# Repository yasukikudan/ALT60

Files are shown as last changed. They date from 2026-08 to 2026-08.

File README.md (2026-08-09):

# ALT60

61キーの60%サイズ手配線メカニカルキーボード。PCBを使わず、3Dプリントしたケースで組み立てる前提で設計している。最初から読みやすい配線設計、それに対応したファームウェア設定、その配線を前提に設計した3Dプリント用ケースを揃えている。このリポジトリはALT60自体の設計仕様であると同時に、Pro Microベースの手配線キーボードなら何にでも使い回せる小さなフレームワークでもある。

## ここに入っているもの

| | |
|---|---|
| [`docs/wiring_plan.html`](docs/wiring_plan.html) | 13×5マトリクスの配線表全体 — 61キーそれぞれがどのピアに乗るか、なぜそうなるか。 |
| [`docs/wiring_layout.html`](docs/wiring_layout.html) | 同じ配線を実際のキー配置に重ねた図 — はんだ付け中に開いておく用。 |
| [`docs/keymap.html`](docs/keymap.html) | 論理キーマップ: ベースレイヤー、Fnレイヤー、JIS/US記号補正。 |
| [`docs/case_design.html`](docs/case_design.html) | 3Dプリント用ケース仕様 — プレート、側壁、ネジボス、MCU用のくぼみ、打鍵傾斜まで全て寸法込み。 |
| [`firmware/`](firmware/) | ファームウェア本体。`keyboard_fw/board_config.h`がALT60固有の設定、`matrix_scan.h`/`keycode_output.h`は汎用。 |
| [`CLAUDE.md`](CLAUDE.md) | AIエージェントによる対話的ピン発見を使って手配線ボードを立ち上げるための指示書 — 別のボードでも使い回せるように書いてある。 |

## キーボード概要

- **61キー**、15U × 5行のレイアウト(Row1=14, Row2=14, Row3=13, Row4=12, Row5=8キー)。
- **スペースキーにスタビライザーなし** — 6.25Uのキーキャップの下に独立したスイッチを2個配置し、マトリクスに結線するのは1個だけ。もう1個は機械的な支持専用のダミースイッチ。
- **フルFnレイヤー**: Fキー、矢印、ナビゲーションクラスタ、メディアキー、独立したグレイブ(`` ` ``、Fn+Z)/チルダ(`~`、Fn+X)。
- **Macモード**(`Fn+Win`でトグル、EEPROM保存): Space両脇のCtrlキーがCmdを送るようになる。
- **実行時JIS/US記号補正**(`Fn+Menu`、EEPROMに保存) — USキーキャップのままWindowsが日本語(JIS)レイアウトになっている環境向け。
- USB経由の**NKRO**、[HID-Project](https://github.com/NicoHood/HID)の`NKROKeyboard`を使用。

## 配線を一言で言うと

列ピン(`D5`〜`D9`)がそれぞれ物理的な行を1本ずつ駆動する。行ピン(`D0`,`D1`,`D2`,`D3`,`D4`,`D10`,`D14`,`D15`,`D16`,`D18`,`D19`,`D20`,`D21`)が行内の左から位置を選ぶ。例外は2つだけ — Backspaceと`\`(それぞれRow1・Row2の14番目のキーで、行ピンが13本しかないため)、Row5の空いている行ピンスロットを間借りする。詳細と理由は[`docs/wiring_plan.html`](docs/wiring_plan.html)を参照。

## ケース

3Dプリント、2パーツ構成: トッププレート(スイッチ穴のみ)とボトムシェル(側壁一体型、小型Pro Micro+ユニバーサル基板用のくぼみ、壁に一体成形したネジボス — バラのスタンドオフ部品なし)。打鍵傾斜は約7.45°(手前18.0mm/奥33.1mm)。壁・ボス・穴すべての寸法を含む全体仕様は[`docs/case_design.html`](docs/case_design.html)を参照。

## ファームウェアのビルド

```bash
arduino-cli core install arduino:avr
arduino-cli lib install "HID-Project"
arduino-cli compile --fqbn arduino:avr:leonardo firmware/keyboard_fw
arduino-cli upload -p <COM_PORT> --fqbn arduino:avr:leonardo firmware/keyboard_fw
```

`firmware/keyboard_fw/board_config.h`は`docs/wiring_plan.html`から直接導いたALT60の目標設定であり、**まだ実機で配線を検証していない**。ALT60を実際に組む場合は`docs/wiring_layout.html`通りに配線したあと、まず`firmware/matrix_scanner/matrix_scanner.ino`を書き込んで、各キーが`board_config.h`の想定通りの(行, 列)に来ているか1つずつ確認してから信用すること — 立ち上げ手順の全体は`CLAUDE.md`を参照。

## このフレームワークで別のボードを組む場合

`firmware/keyboard_fw/matrix_scan.h`と`keycode_output.h`は完全に汎用で、ボード固有の情報は全て`board_config.h`から読み込む。`firmware/matrix_scanner/matrix_scanner.ino`が対話的なピン発見ツール。`CLAUDE.md`にはその全工程(実際に時間を食った失敗パターンも含めて)がまとめてあるので、AIエージェントが別の人の手配線ボードでも同じ立ち上げ手順を再現できる。

## ライセンス

BSD 3-Clause — [`LICENSE`](LICENSE)参照。公開前に著作権者名を記入すること。

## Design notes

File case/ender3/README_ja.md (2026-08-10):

# ALT60ケース Ender-3左右分割版

`case/original` のFIX済み原寸マスターを変更せず、Ender-3で出力できるようにトップとボトムを中央で左右分割した派生版です。

- トッププレートとボトムケースは左右2分割、合計4パーツです。
- 中央4本のM2.5ネジと完全なネジ受けを最優先し、丸棒・穴は位置合わせの補助とします。
- 独立した台座・柱・ブロックは作らず、底板と前後側壁へ横向きの丸棒と穴を直接形成します。
- 接手は前壁2本、底面6本、後壁2本の合計10本です。
- 丸棒を左・右から交互に一体成形し、反対側には対応する横穴を設けています。
- 丸棒は直径3.2 mm、差し込み長8.0 mm、穴は直径3.5 mm、深さ9.0 mm、先端面取り0.5 mmです。
- 通常の底厚2.5 mmは分割線付近で6 mm、通常の壁厚3 mmは前後壁の分割線付近で6 mmへ増厚します。
- 底板の丸棒・穴の中心は増厚後6 mmの板厚中央、底面からZ=3.0 mmです。前後壁の丸棒・穴も増厚後6 mmの壁厚中央へ置きます。
- 増厚範囲は中央から左右20 mmで、左右16〜20 mmの範囲を斜面にして滑らかにつなぎます。
- 補強は内側だけに加え、ケース外形は変更しません。
- 外枠の外側へ出る突起や別体部品はありません。
- 分割部は0.30 mmの組立クリアランスを設けています。
- 中央部の前後に左1本・右1本ずつ、合計4本のM2.5縦ネジを配置しています。
- ネジ位置は X=-8/+8 mm、Y=-45/+45 mmです。
- トップ側にはM2.5通し穴と局所補強、ボトム側には欠けない完全なネジ受けを設けています。
- トッププレートから垂直にネジを締め、左右ボトムを同時に固定します。
- 全出力パーツは最大外寸200 mm未満であることを自動検査します。

組立時は左右ボトムを同じ高さに合わせ、10本の丸棒を対応する穴へ水平方向から同時に差し込みます。その上に左右トップを載せ、中央4本のM2.5ネジを先に締めてから外周ネジを締めます。初回は直径差0.3 mmで試し刷りし、プリンタの実寸に応じて `SOCKET_D` を調整してください。

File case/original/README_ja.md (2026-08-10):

# ALT60ケース v1

`alt60_case.py` は、ALT60リポジトリの物理配列を使ったCadQuery 2.xスクリプトです。

- 外形: 305.75 × 115.25 mm
- Cherry MX穴: 14 × 14 mm（6.25Uスペースバーは中央＋左右±50 mmの支持穴）
- 壁3 mm、床2.5 mm、トッププレート1.6 mm
- トップ／ボトム外周角: R3 mm
- ケース固定: M2.5 × 12、通し穴2.9 mm、ヒートセットインサート用3.5 mm下穴（使用するインサートに合わせて要調整）
- ケースネジ軸: トップから机に対して鉛直（傾斜プレートに対して約6.9°の斜め穴）
- トップネジ周囲: φ10 mm、局所厚約4 mm（通常部1.6 mm）
- ボトム受けボス: φ10 mm
- 60 × 70 mmユニバーサル基板: 後方中央、ケースと平行に傾斜、M2.5 × 4
- 基板下面から内底まで: 15 mm
- USB開口: 後壁中央、18 × 10 mm、R2（Micro-USB／USB-Cケーブルの樹脂モールド用余裕を含む）
- ケース高: 前14.0 mm、後28.0 mm（60×70 mm基板の前縁下に底厚を残すため）
- ユニバーサル基板とESP32: トッププレートと平行に約7.45°傾斜
- 写真の60×70 mm基板固定: φ7 mmのM2.5ボス4本、下穴2.0 mm（暫定で中心から左右±25、前後±30 mm）
- 基板の全周を開放し、四方から配線を通せる構造
- Ender-3左右分割対策: 前後とも分割線の中心X=0に固定点（左右半分ずつ造形）
- 幅の1/4・3/4位置（中心から約±76.4 mm）にも前後それぞれ固定点
- 60×70 mm基板中心はX=-108 mm（範囲X=-138〜-78 mm、完全に左半分側）
- ESP32とUSBは基板内でさらに左へ12 mm寄せてX=-120 mm
- 左後の1/4位置ネジだけX=-70 mmへ調整し、基板と両側ボスの間に約3 mm確保
- ピン逃げ: 中央54×64 mm、基板下面から深さ4 mm
- ESP32実装想定: ピンヘッダをユニバーサル基板へ直接はんだ付け
- ESP32上側実装高: 8 mm、切断後の裏ピン逃げ: 3 mm
- ESP32ピン専用逃げ: 約30×48 mm、深さ3 mm（基板中央）

## 生成

```powershell
python alt60_case.py
```

フルサイズのSTEP/STLと、Ender-3向け左右分割STLを同じフォルダに出力します。分割版は中央に0.30 mmの組立隙間を設けた単純二分割です。初号機では接着または裏面ブリッジ板で結合してください。

## 印刷前に確認する値

1. 実物ユニバーサル基板の穴位置（初期値は中心から±30、±20 mm）
2. ESP32のUSB中心高さ（初期値はユニバーサル基板上面から10.3 mm）
3. M2.5ヒートセットインサート指定の下穴径
4. 14 mm MX穴のテスト片（プリンタにより0.1〜0.2 mm補正）

元ALT60寸法では基板下面15 mmを確保できません。傾斜基板の前縁側が最小になるため、ピンを短く切り、初回印刷前に実物との干渉を確認してください。CQ-editorでは組立状態と分解状態を同時表示します。

分割STLはEnder-3のベッドに収まりますが、トッププレートは平置き、ボトム左右は底面を下にして印刷してください。トッププレートは長尺なので、反り止めとしてブリムを推奨します。

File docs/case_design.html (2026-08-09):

# ALT60(オールライフタイムキーボード) — 3Dプリント用ケース設計仕様

3Dプリンター(STL)前提の設計。バラのスタンドオフ部品は使わず、側壁を持つ完全な一体シェルとしてケースを構成する。トッププレートは側壁の上に直接乗せてネジ止めするだけで、側壁自体がスイッチ/配線用の空洞を作る。

①トッププレート(スイッチ穴+ネジボス用の縁)、②ボトムシェル(側壁+床+Pro Micro/基板用のくぼみを一体成形)の2パーツで完結する。

一般的なキーボードと同じく手前が低く、奥(背面)が高い傾斜を付ける。ケース奥行き115.25mm(側壁+ベゼル込み)に対し、手前18.0mm/奥33.1mm(角度約7.45°)を採用した。

厚み・高さ諸元(Z方向)
項目 | 寸法 | 備考
打鍵傾斜角 | 約7.45 ° | 手前18.0mm/奥33.1mmの高さ差(奥行き115.25mm)から算出
ケース全体高さ・手前(Row5/スペース側) | 18.0 mm | 底面(接地面)からトッププレート上面まで
ケース全体高さ・奥(Row1/USB側) | 33.1 mm | 手前18.0mm + 奥行き115.25mm × tan(7.45°)
ベゼル幅(壁内側〜スイッチ列) | 7.0 mm | 四辺とも確保。ネジボスがスイッチ穴と干渉しないための余白
トッププレート厚み | 3.0 mm | MX穴がスナップで保持できる標準的な厚み(傾斜方向に対して一定)
側壁の高さ(内部空洞の深さ) | 10.0 mm | スイッチ本体+手配線の取り回し分。傾斜方向に対して一定、トッププレートはこの壁の上端に直接乗る
側壁の厚み | 3.0 mm | シェル外周を1周する壁
ネジボス外径 | 8.0 mm | 壁の外面に接する位置に配置(壁厚みだけに頼らない、独立して自立する太さ)
ネジ穴・トッププレート側(クリアランス) | φ2.2 mm | M2ねじの軸が自由に通る貫通穴。ここはネジを受けない
ネジ下穴・シェル側(セルフタップ) | φ1.6 mm | M2セルフタップねじがここに食い込んで固定される。ボス高さ=側壁高さ10.0mmぶん深さがあるので保持力は十分
ボトムシェル床面の厚み・手前 | 5.0 mm | 18.0 − プレート3.0 − 壁10.0
ボトムシェル床面の厚み・奥 | 20.1 mm | 33.1 − プレート3.0 − 壁10.0。手前から奥へ直線的に厚みが増える
くぼみの深さ | 6.0 mm | Pro Micro+ユニバーサル基板+はんだ面のクリアランス込み

USBコネクタ用切り欠き
項目 | 寸法 | 備考
幅 | 10.0 mm | Micro-USB-B(実測幅約7.5mm)・USB-C(実測幅約8.5mm)どちらでも余裕を持って通る幅
高さ | 5.0 mm | コネクタ実高さ+印刷公差分の余裕
角丸半径 | 1.0 mm | 応力集中を避けるための丸め
切り欠き位置 | 側壁を貫通 | 壁厚3.0mm+くぼみ縁までを通し、背面(Row1側)の壁に開ける

キーキャップ外形(参考線)

スイッチ穴(結線あり)

スイッチ穴(支持のみ・未結線)

側壁(トッププレートは縁の帯、シェルは実際の壁)

ネジボス(外径8.0mm、壁に接して自立、M2、8箇所)

くぼみの外形(一体成形)

USB切り欠き

## ①トッププレート(スイッチ穴+ネジボス用の縁、厚み3.0mm)

スイッチ面285.75 × 95.25mm + 四辺7.0mmベゼル + 側壁厚み3.0mm = 外形305.75 × 115.25mm。

## ②ボトムシェル(側壁+床+くぼみを一体成形)

トッププレートと同じ外形(305.75 × 115.25mm)。側壁が空洞を作り、くぼみは床に彫り込む。バラのスタンドオフ部品は不要。

## ③断面イメージ(傾斜込み、組み立て時)

底面は水平(接地面)、手前18.0mm・奥33.1mmで約7.45°の傾斜。床厚は手前5.0mm→奥20.1mmと直線的に変化し、くぼみは厚みが確保できる奥側に配置。

### スペーサー(標準オフ部品)なしの完全ケース

以前案のバラのスタンドオフ(円柱ピンでプレートと底板を浮かせる方式)をやめ、側壁を持つ一体シェルに変更。側壁がそのままスイッチ/配線用の空洞を作り、トッププレートは側壁の上端に直接ネジ止めする。パーツ数が減り、組み立て時に位置決めもしやすい。

### 打鍵傾斜(手前が低く奥が高い)

底面(接地面)は水平のまま、プレート厚み3.0mm・壁高さ10.0mmは傾斜方向に対して一定に保ち、床の厚みだけを手前5.0mm→奥20.1mmへ直線的に変化させることで約7.45°の傾斜を作る。折りたたみ式の脚は使わず、ケース自体の形状で傾斜を固定する設計。

### スペースキー: 2スイッチ支持方式

6.25U幅の下にスイッチを2個配置(中心から左右1.25Uずつ)。結線するのは1個だけ(既存の行D20・列index4、ファームウェア変更なし)。もう1個は電気的に未接続で、キーキャップを水平に支えるためだけの「ダミースイッチ」。スタビライザーワイヤーが不要になる。

### ネジボスの強度(壁の中央に置かない)

初期案は壁厚3.0mmの中心線上にボスを置いていたため、実際には壁からはみ出た部分に強度がなく、印刷しても割れる設計になっていた。今回、ボス自体を外径8.0mmの独立した円柱にして壁の外面に接する位置に置き直し、壁の厚みだけに頼らずボス単体で強度が出るようにした。あわせて壁内側とスイッチ穴の間に7.0mmのベゼルを確保し、ボスがスイッチ穴と干渉しないようにした。四隅4箇所+上辺(Row1側)内側2箇所+左右辺中央2箇所の計8箇所、トッププレートとシェル両方で同じ位置に穴を開けて揃える。

### ネジ穴とネジを受ける穴は別物

トッププレート側はクリアランス穴(φ2.2mm)でネジの軸が自由に通るだけ。実際にネジを受けて締結するのはシェル側の下穴(φ1.6mm、セルフタップ用)で、ボスの高さ=側壁高さ10.0mm分の深さがあるので保持力も十分。同径の穴を両方に開けるとネジが効かない/プレートが浮くので、必ず径を変える。

### くぼみは一体成形、奥側の厚い床に配置

3Dプリントは平面から直接くぼみを彫り込めるので、レーザー加工向けの「フレーム層+底板の貼り合わせ」は不要。傾斜によって床が自然に厚くなる奥側(Row1/USB側)にくぼみを置いたため、以前のような局所的な底面の厚み増し(バルジ)は不要になった。印刷はくぼみ・スイッチ穴が上向きになる姿勢ならサポート材なしで出せる。

### 基板・Pro Microのサイズ

小型ユニバーサル基板 60×40mm、Pro Micro 18×33mmを想定したくぼみ・取り付け穴。実際に使う基板寸法とネジ穴ピッチ(ユニバーサル基板は2.54mm格子)に合わせて微調整する。

### 配線

行13本+列5本=計18本の配線がすべてこのくぼみへ集まる想定。各スイッチの実際の結線経路は手配線のため個別には図示していない(keymap_by_pin.md参照)。側壁で囲まれた高さ10mmの空洞がトッププレート裏の配線スペースになる。

### 穴寸法・印刷メモ

スイッチ穴14×14mm、1Uピッチ19.05mm(FDM印刷はレーザーのようなケルフ補正は不要。穴が小さめに出る場合はスライサー側で0.1〜0.2mmのホール補正を使う)。ネジボス穴はM2ねじ想定(セルフタップ or 圧入インサート)。

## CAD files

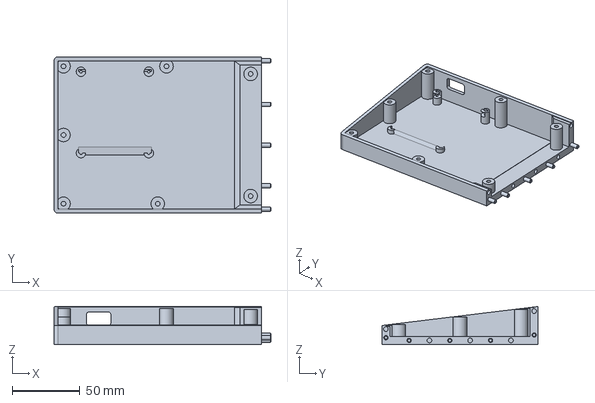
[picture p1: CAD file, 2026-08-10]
case/ender3/bottom/bottom_left.step
159.9 x 115.2 x 28.0 mm

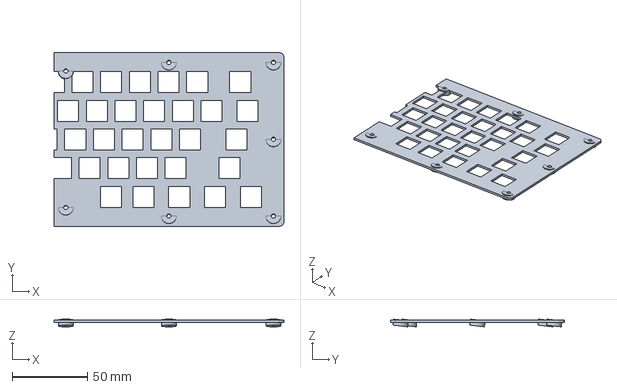
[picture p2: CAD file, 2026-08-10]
case/ender3/top/top_right.step
152.7 x 115.2 x 5.18 mm

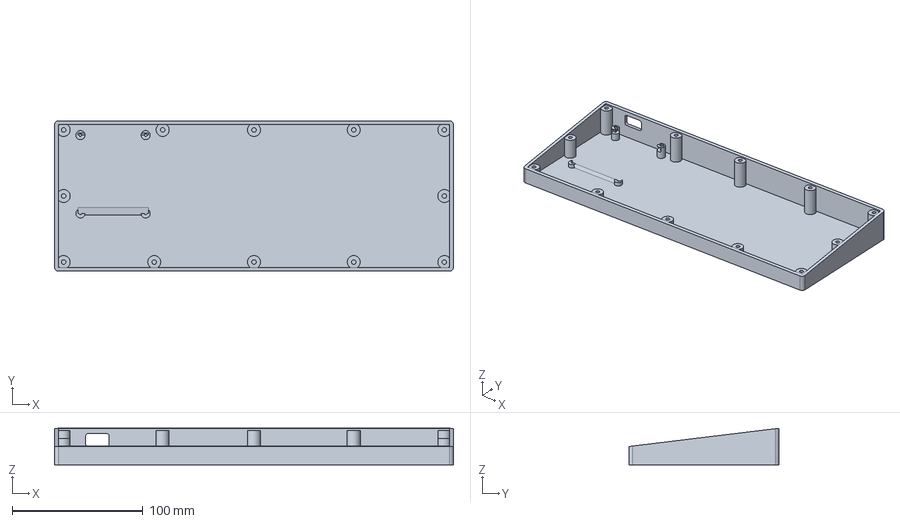
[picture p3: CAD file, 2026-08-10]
case/original/bottom_case/bottom_case.step
305.8 x 115.2 x 28.0 mm

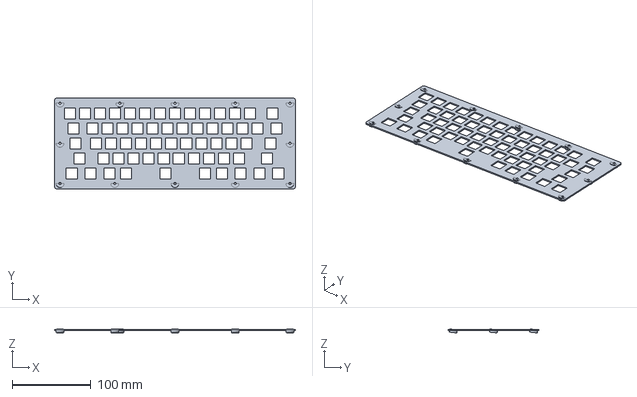
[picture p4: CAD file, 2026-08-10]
case/original/top_plate/top_plate.step
305.8 x 115.2 x 5.18 mm

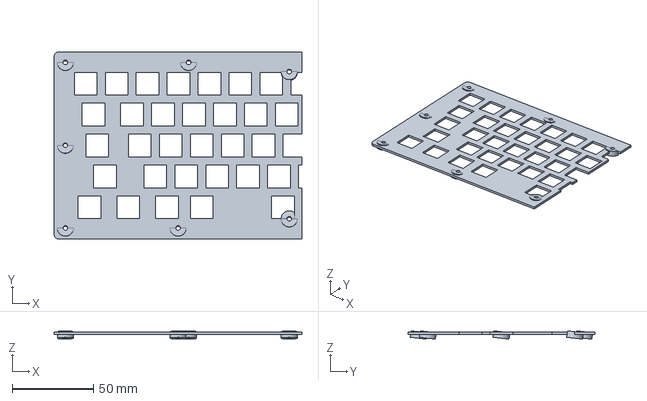
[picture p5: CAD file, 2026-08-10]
case/ender3/top/top_left.step
152.7 x 115.2 x 5.18 mm

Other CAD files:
case/ender3/bottom/bottom_right.step
case/ender3/bottom/bottom_left.stl
case/ender3/bottom/bottom_right.stl
case/ender3/top/top_left.stl
case/ender3/top/top_right.stl
case/original/bottom_case/bottom_case.stl
case/original/top_plate/top_plate.stl

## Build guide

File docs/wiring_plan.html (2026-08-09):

# ALT60 — 配線プラン

61キー・60%レイアウトの手配線マトリクス仕様。列(5本)= 物理的な行(Row1〜5)、行ピン(13本)= 各行内の左からの位置という単純な規則だけで、配線を見ればどのキーがどこに繋がるか誰でも判別できる。

Pro Micro(ATmega32U4)はGPIOが18本しかなく、行13本+列5本でちょうど使い切る。Row1・Row2はそれぞれ14キーあるため、行ピン13本だけでは1本足りない。Row5(8キーしか使わない)の余っている行ピンスロットを2つ借用し、Backspaceと\だけ例外としてRow5用の列(D9)に間借りさせることで、全61キーを過不足なく収めている。

Row5だけは単純な0〜7の左詰めにしていない。スペースキーが6.25U分の幅を1スロットで占有するため、素直に左から詰めるとMenu/Fnなど後半のキーが物理的にはボードの右端付近にあるのに、行ピン番号は若いまま(=他の行では左寄りの位置を指す番号)になり、配線を右へ右へと引き延ばす必要が出る。そこでRow5の8キーは、各キーの物理位置に一番近い行ピン番号を選んで割り当て、後半キーの引き延ばしを最小限にしている。

通常(列=そのキーの物理行)

例外(Row5の空きスロットに間借り)

未使用スロット

## 配線マトリクス(行ピン × 列ピン)

列(D5〜D9)がそのまま物理的な行(Row1〜Row5)に対応。行ピン(D0〜D21)は各行内の左からの位置。

### 列 = 物理的な行

col0=D5→Row1 / col1=D6→Row2 / col2=D7→Row3 / col3=D8→Row4 / col4=D9→Row5。この5本さえ間違えなければ「どの行を触っているか」が配線から直読できる。

### 行ピン = 行内の位置

D0,D1,D2,D3,D4,D10,D14,D15,D16,D18,D19,D20,D21の13本を左から順に position 0〜12 に割り当て。Row1/Row2はposition 0〜12で13キー分埋まり、14番目のキー(Backspace/\)だけが例外。

### 例外は2つだけ

Backspace → (D15, D9)、\ → (D16, D9)。Row5は8キー分(position 0,1,3,6,9,10,11,12)しか使わないので、空いているposition 7・8(D15・D16)のRow5列(D9)スロットを間借りする。他のどのキーとも衝突しない。

### Row5の位置一覧

position 0=Win/Caps, 1=Alt, 3=Ctrl, 6=Space, 7=Backspace(例外), 8=\(例外), 9=Ctrl, 10=Alt, 11=Menu, 12=Fn。position 2・4・5は未使用。

### スペースキーの2スイッチ

Row5 position 6 (D14, D9) が結線するスイッチ。ダミー(未結線)側はこのマトリクスに現れない(電気的に存在しないため)。

### ファームウェアへの反映

この表がそのままboard_config.hのrowPins[](D0,D1,D2,D3,D4,D10,D14,D15,D16,D18,D19,D20,D21の順)・colPins[](D5,D6,D7,D8,D9)・keymap[][]の並びになる。配線とコードが同じ順序・同じ規則で対応するので、あとから見返しても迷わない。

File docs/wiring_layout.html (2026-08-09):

# ALT60 — 配線レイアウト図

実際のキー配置の上に配線ピンを直書きした、はんだ付け作業用の図。左端の緑ラベルがその行全体をまとめる列ワイヤー(物理的な行1本につき1本)。各キーの銅色の小さい数字がその行内で使う行ワイヤーのピン番号。

配線は「同じ行の全キーを1本の列ワイヤーで直列に繋ぎ、各キーからそのポジション番号の行ワイヤーへ1本ずつ配線する」という通常のマトリクス配線そのまま。

最下段(Row5)だけはD0から順に詰めていない。スペースキーが6.25U分を1スロットで占有するため、単純に左詰めするとCtrl/Alt/Menu/Fnなど右側のキーほど配線が実際の位置から遠いピンへ延ばされてしまう。ここでは各キーの物理位置に一番近い行ピンを選んでいるので、右へ行くほど配線を大きく引き延ばす必要はない。

D0Key 通常キー(上:行ワイヤーのピン/下:キー)

D15→D9Key 例外キー(自分の行の列ワイヤーではなく、Row5の列D9に配線)

列
D5

D0Esc

D11

D22

D33

D44

D105

D146

D157

D168

D189

D190

D20-

D21=

D15→D9Backspace

列
D6

D0Tab

D1Q

D2W

D3E

D4R

D10T

D14Y

D15U

D16I

D18O

D19P

D20[

D21]

D16→D9\

列
D7

D0Ctrl

D1A

D2S

D3D

D4F

D10G

D14H

D15J

D16K

D18L

D19;

D20'

D21Enter

列
D8

D0Shift

D1Z

D2X

D3C

D4V

D10B

D14N

D15M

D16,

D18.

D19/

D20Shift

列
D9

D0Win

D1Alt

D3Ctrl

D14Space

D18Ctrl

D19Alt

D20Menu

D21Fn

### 列ワイヤー(5本)

同じ行の全キーを1本のワイヤーで直列に繋ぎ、行の端でPro Microの列ピンへ。D5=Row1、D6=Row2、D7=Row3、D8=Row4、D9=Row5。

### 行ワイヤー(13本)

各キーの行ワイヤー側の足を、そのポジション番号のピンへ。D0,D1,D2,D3,D4,D10,D14,D15,D16,D18,D19,D20,D21の13本を、行をまたいで使い回す(例: D0は各行の一番左のキーに共通で使われる)。

### 例外は2箇所だけ

Backspace(D15→D9)と\(D16→D9)は、自分の行(D5/D6)ではなくRow5の列D9へ配線する。Pro Microのピンが1本足りず、Row5の空きスロットを間借りしているため。配線時にここだけ見落とすと動かないので要注意。

### スペースキー

2スイッチのうち結線するのは1個だけ(D3/D9)。もう1個は電気的に未接続で、キーキャップの水平支持だけが目的。

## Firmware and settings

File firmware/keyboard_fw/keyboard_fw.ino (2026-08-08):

#include "board_config.h"
#include "matrix_scan.h"
#include "keycode_output.h"

const unsigned long CHATTER_REPORT_INTERVAL_MS = 2000;

void setup() {
  Serial.begin(9600); // only used if a terminal is actually connected -- see printChatterStats()
  MatrixScan::begin();
  KeycodeOutput::begin();
}

void loop() {
  static unsigned long lastScan = 0;
  static unsigned long lastChatterReport = 0;
  unsigned long now = millis();

  if (now - lastScan >= BoardConfig::SCAN_INTERVAL_MS) {
    lastScan = now;
    MatrixScan::scan(KeycodeOutput::handleKeyEvent);
    KeycodeOutput::refreshJisLed();
  }

  if (now - lastChatterReport >= CHATTER_REPORT_INTERVAL_MS) {
    lastChatterReport = now;
    MatrixScan::printChatterStats();
  }
}

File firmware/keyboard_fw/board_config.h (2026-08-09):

#pragma once
#include "HID-Project.h"

// ============================================================================
// BOARD CONFIG for ALT60.
//
// This is the *target* configuration derived from ALT60's wiring plan
// (see ../docs/wiring_plan.html and ../docs/wiring_layout.html) -- it has
// NOT been verified against a physically wired board yet. Follow the
// bring-up workflow in ../CLAUDE.md: flash matrix_scanner/, confirm each
// (row, col) pair actually lands where this file expects, then trust it.
// If anything disagrees, the physical wiring or this file is wrong --
// don't assume this file is correct just because it's here.
//
// Wiring rule this config follows (see docs/wiring_plan.html for the full
// rationale): colPins[] index = physical keyboard row (Row1..Row5, one
// pin per row). rowPins[] index = left-to-right position within a row --
// except Row5, whose 8 keys are NOT simply positions 0-7: the spacebar
// eats 6.25U in one slot, so Row5's later keys sit far to the right
// physically, and using 0-7 would force those row-pin wires into long
// rightward detours. Row5 instead uses whichever position index sits
// physically closest to each key (0,1,3,6,9,10,11,12), leaving 7 and 8
// genuinely free for the two documented exceptions (Backspace, \) --
// Row1/Row2 have 14 keys each but there are only 13 row pins, so those
// two borrow Row5's column at those otherwise-unused slots. Full
// rationale and the physical-position math: docs/wiring_plan.html.
// ============================================================================

namespace BoardConfig {

#define FN_LAYER 0xFF // sentinel: this position is Fn, never sent as HID

// --- Matrix wiring ---------------------------------------------------------
#define NUM_ROWS 13
#define NUM_COLS 5

// Row pins = position-within-row 0..12, left to right.
const uint8_t rowPins[NUM_ROWS] = {0, 1, 2, 3, 4, 10, 14, 15, 16, 18, 19, 20, 21};
// Col pins = physical row, Row1..Row5.
const uint8_t colPins[NUM_COLS] = {5, 6, 7, 8, 9};

// Shift lives in col3 (Row4), Fn lives in col4 (Row5) -- dispatch those
// columns first each scan pass to reduce same-row modifier-timing races.
const uint8_t PRIORITY_COL_A = 3;
const uint8_t PRIORITY_COL_B = 4;

// --- Debounce / scan rate ---------------------------------------------------
const unsigned long DEBOUNCE_MS = 5;
const unsigned long SCAN_INTERVAL_MS = 1; // ~1000Hz
const unsigned long CHATTER_WINDOW_MS = 300; // stats only, see matrix_scan.h

// --- Base keymap -------------------------------------------------------------
// keymap[row][col], 0 = no key at that position, FN_LAYER = this position
// is the Fn key itself (sends nothing on its own).
// row = position-within-row (0..12), col = physical row (0=Row1..4=Row5).
// col4 (Row5) positions are NOT a simple 0-7 left-to-right run like the
// other columns. The spacebar occupies 6.25U in one slot, so Row5's later
// keys (Ctrl/Alt/Menu/Fn) sit far to the right physically -- using
// positions 0-7 would force every one of those row-pin wires to detour
// increasingly far right to reach them. Instead each Row5 key uses the
// row-pin index whose typical physical location (in the other columns)
// is closest to that key's real position: 0,1,3,6,9,10,11,12 (skipping
// 2,4,5 -- genuinely unused -- and 7,8, borrowed below by Backspace/\).
const uint8_t keymap[NUM_ROWS][NUM_COLS] = {
  /* pos0  */ {KEY_ESC,   KEY_TAB,        KEY_LEFT_CTRL, KEY_LEFT_SHIFT, KEY_CAPS_LOCK}, // col4: base=Caps(US)/Zenkaku-Hankaku(JIS); Fn+this=Win/Meta
  /* pos1  */ {KEY_1,     KEY_Q,          KEY_A,         KEY_Z,          KEY_LEFT_ALT},
  /* pos2  */ {KEY_2,     KEY_W,          KEY_S,         KEY_X,          0},
  /* pos3  */ {KEY_3,     KEY_E,          KEY_D,         KEY_C,          KEY_LEFT_CTRL},
  /* pos4  */ {KEY_4,     KEY_R,          KEY_F,         KEY_V,          0},
  /* pos5  */ {KEY_5,     KEY_T,          KEY_G,         KEY_B,          0},
  /* pos6  */ {KEY_6,     KEY_Y,          KEY_H,         KEY_N,          KEY_SPACE},
  /* pos7  */ {KEY_7,     KEY_U,          KEY_J,         KEY_M,          KEY_BACKSPACE},   // col4: exception, borrows Row5's unused slot
  /* pos8  */ {KEY_8,     KEY_I,          KEY_K,         KEY_COMMA,      KEY_BACKSLASH},   // col4: exception, borrows Row5's unused slot
  /* pos9  */ {KEY_9,     KEY_O,          KEY_L,         KEY_PERIOD,     KEY_RIGHT_CTRL},
  /* pos10 */ {KEY_0,     KEY_P,          KEY_SEMICOLON, KEY_SLASH,      KEY_RIGHT_ALT},
  /* pos11 */ {KEY_MINUS, KEY_LEFT_BRACE, KEY_QUOTE,     KEY_RIGHT_SHIFT, KEY_MENU},       // Fn+Menu toggles JIS mode
  /* pos12 */ {KEY_EQUAL, KEY_RIGHT_BRACE, KEY_RETURN,   0,              FN_LAYER},        // Fn: sends nothing on its own
};
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

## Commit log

2026-08-08 Initial ALT60 design: README, wiring plan, keymap, case design, framework firmware
    Wiring, keymap, and case documents exported from the design work done for
    ALT60 (the next-gen rebuild of the ALTKB hand-wired prototype). Firmware
    carries over the generic matrix_scan.h/keycode_output.h framework
    unchanged, with a new board_config.h derived from the wiring plan --
    not yet verified against a physically wired board.
2026-08-09 Rework Row5 wiring to avoid rightward wire stretching past the spacebar
    Row5's keys were previously assigned row-pin positions 0-7 left to right,
    like every other row. But the spacebar eats 6.25U in a single slot, so
    Row5's later keys (Ctrl/Alt/Menu/Fn) sit much further right physically
    than their position number implies -- every row-pin wire past the
    spacebar had to detour increasingly far right to reach them.
    Reassign Row5 to the position index whose typical physical location (in
    the other, mostly-1U rows) is closest to each key's real position
    (0,1,3,6,9,10,11,12 instead of 0-7), and move the Backspace/backslash
    exceptions from Row5's now-used 8/9 slots to the freed-up 7/8 slots.
    Updated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
    [board_config.h]
2026-08-09 Add Mac mode: Fn+Win toggles Cmd/Ctrl swap on the Space-adjacent Ctrl keys
    Fn+Win-position previously sent a momentary Win/Meta keypress. Repurposed
    it to toggle a persistent "Mac mode" instead: while on, the two Ctrl keys
    beside Space send Cmd (GUI) rather than Ctrl, matching where Mac users
    expect Cmd for thumb-driven shortcuts. The HHKB-style Caps-position Ctrl
    is deliberately left alone so real Ctrl (emacs bindings, terminal Ctrl-C)
    stays reachable even in Mac mode. Not persisted to EEPROM -- resets to
    off on every boot, so it can't silently stay on when the board moves back
    to a PC. Applied the same change to both the ALTKB working firmware and
    the ALT60 target config; both recompile cl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
    [board_config.h, keycode_output.h]
2026-08-09 Persist Mac mode to EEPROM (address 1)
    User asked for the toggle to survive a reboot after all, matching JIS
    mode's pattern. Defaults OFF on an erased board (unlike JIS mode's
    default-ON), only turns on at boot after an explicit prior toggle wrote
    a literal 1.
    [keycode_output.h]
2026-08-09 Remove HHKB references and ALTKB-prototype origin story
    The public repo/docs should describe ALT60 on its own terms, not as
    "inspired by HHKB" or "the do-over of an earlier ALTKB prototype".
    Removed HHKB citations from the README, wiring plan, keymap, case
    design docs, and a code comment; removed the README's ALTKB origin
    paragraph entirely. Numeric design choices (typing angle, Fn-layer
    layout) are kept, just no longer attributed.
    [board_config.h]
2026-08-10 Round out Mac mode: fix Consumer/volume keys, bypass JIS while active, remap PrintScreen
    - Consumer.begin() now runs at boot -- without an initial report, some
    hosts (macOS in particular) never register the Consumer Control HID
    collection, so volume/media keys silently do nothing.
    - Added jisActive() = jisMode && !macMode, and switched every JIS
    compensation handler to use it. JIS symbol compensation only makes
    sense against a JIS-interpreting Windows host; it has nothing to
    compensate for on a Mac. The jisMode toggle/LED/EEPROM value are
    untouched, so leaving Mac mode restores whatever JIS setting was set.
    - PrintScreen (Fn+I) sends Cmd+Shift+3 (full-screen screenshot) instead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
    [keycode_output.h]
2026-08-10 Add printable ALT60 keyboard case
    [bottom_case.step, bottom_case.stl, bottom_left.step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]
